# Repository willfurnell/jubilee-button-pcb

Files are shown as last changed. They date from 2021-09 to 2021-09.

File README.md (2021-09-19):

# jubilee-button-pcb

PCB for the Jubilee Line button replacement PCB

Created using KiCad

Check out some sample code here: https://github.com/willfurnell/jubilee-hue

You should be able to send this straight off to JLCPCB if you want one - or contact me as I did a bulk order and may have some to post out!

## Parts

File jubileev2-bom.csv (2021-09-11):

Reference | Quantity | Value | Footprint | LCSC Part #
C1, C2, C3, | 3 | 10uF | SMD_5x5.4mm | C72487
C5, | 1 | 10uF | 0805 | C15850
C6, C9, C11, C12, | 4 | 0.1uF | 0805 | C49678
C7, C8, | 2 | 47pF | 0805 | C14857
C10, | 1 | 4.7uF | 0805 | C1779
D1, | 1 | POWER_LED | 0805 | C2297
D2, | 1 | D_Schottky | SOD-123 | C8598
D3, | 1 | D | SOD-123 | C8598
D4, | 1 | ESP_LED | SOD-123 | C8598
D5, | 1 | D_Small | 0805 | C2297
Q1, Q2, | 2 | MMBT3904 | SOT-23 | C20526
Q3, | 1 | PZT2222A | SOT-223 | C189428
R1, | 1 | 1K | 0805 | C17513
R2, R3, R4, R5, R8, R9, | 6 | 10K | 0805 | C17414
R6, R7, | 2 | 27 | 0805 | C17544
R10, | 1 | 5K6 | 0805 | C28636
R11, | 1 | 50 | 0805 | C17408
R12, | 1 | 100R | 0805 | C17408
SW1, | 1 | BOOT | SMD-4_6.0x6.0x4.5P-1 | C136669
SW2, | 1 | RESET | SMD-4_6.0x6.0x4.5P-1 | C136669
U1, | 1 | AMS1117-3.3 | SOT-223 | C6186
U2, | 1 | AMS1117-5.0 | SOT-223 | C6187
U3, | 1 | ESP32-WROOM-32D | SMD-38_EP_18.0x25.5x1.27P | C473012
U4, | 1 | FT231XQ | QFN-20_EP_4.0x4.0x0.5P | C132159
U5, | 1 | 74HC14 | SOIC-14_3.9x8.7x1.27P | C5605

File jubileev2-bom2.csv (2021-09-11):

Reference | Quantity | Value | Footprint | LCSC Part #
C1, C2, C3, | 3 | 10uF | SMD_5x5.4mm | C72487
C4, C6, | 2 | 22pF | 0805 | C1804
C5, | 1 | 10uF | 0805 | C15850
C7, | 1 | 100nF | 0805 | C49678
C12, | 1 | 0.1uF | 0805 | C49678
D1, | 1 | POWER_LED | 0805 | C2297
D2, | 1 | D_Schottky | SOD-123 | C8598
D3, | 1 | D | SOD-123 | C8598
D4, | 1 | ESP_LED | 0805 | C2297
D5, | 1 | D_Small | SOD-123 | C8598
Q1, Q2, | 2 | MMBT3904 | SOT-23 | C20526
Q3, | 1 | PZT2222A | SOT-223 | C189428
R1, | 1 | 1K | 0805 | C17513
R2, R3, R4, R5, R8, R9, | 6 | 10K | 0805 | C17414
R10, | 1 | 5K6 | 0805 | C28636
R11, | 1 | 50 | 0805 | C17408
R12, | 1 | 100R | 0805 | C17408
SW1, | 1 | BOOT | SMD-4_6.0x6.0x4.5P-1 | C136669
SW2, | 1 | RESET | SMD-4_6.0x6.0x4.5P-1 | C136669
U1, | 1 | AMS1117-3.3 | SOT-223 | C6186
U2, | 1 | AMS1117-5.0 | SOT-223 | C6187
U3, | 1 | ESP32-WROOM-32D | SMD-38_EP_18.0x25.5x1.27P | C473012
U4, | 1 | CH340G | SOIC-16_3.9x9.9x1.27P | C14267
U5, | 1 | 74HC14 | SOIC-14_3.9x8.7x1.27P | C5605
Y1, | 1 | 12Mhz | SMD-3225_4P | C9002

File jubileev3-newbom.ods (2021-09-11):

Reference | Footprint | Quantity | Value | LCSC Part #
R3 | 0805 | 1 | 4.7K | C17673 (https://lcsc.com/product-detail/Chip-Resistor-Surface-Mount_Uniroyal-Elec-0805W8F4701T5E_C17673.html/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)
IC1 | QFN-24_EP_4.0x4.0x0.5P | 1 | CP2104-F03-GMR | C47742 (https://lcsc.com/product-detail/USB_SILICON-LABS_CP2104-F03-GM_CP2104-F03-GM_C47742.html/?href=jlc-SMT)
C11,C3,C2,C1,C5 | 0805 | 5 | 10uF | C15850 (https://lcsc.com/product-detail/Multilayer-Ceramic-Capacitors-MLCC-SMD-SMT_SAMSUNG_CL21A106KAYNNNE_10uF-106-10-25V_C15850.html/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)
C7 | 0805 | 1 | 0.1uF | C49678
C6,C4,C10,C9,C8,C12 | 0805 | 6 | 0.1uF | C49678
ANT1 | SMD-38_EP_18.0x25.5x1.27P | 1 | ESP32-WROOM-32D | C473012
IC2 | SOIC-14_3.9x8.7x1.27P | 1 | 74HC14D,653 | C5605
R12 | 0805 | 1 | 100R | C17408 (https://lcsc.com/product-detail/Chip-Resistor-Surface-Mount_Uniroyal-Elec-0805W8F1000T5E_C17408.html/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)
D4 | 0805 | 1 | ESP_LED | C2297
R2,R4,R5,R8,R9 | 0805 | 5 | 10K | C17414
F1 | 1206 | 1 | Polyfuse | C151162 (https://lcsc.com/product-detail/PTC-Resettable-Fuses_Littelfuse-1206L050-15YR_C151162.html/?href=jlc-SMT)
D5 | SOD-123 | 1 | D_Small | C8598
D3 | SOD-123 | 1 | D | C8598
D2 | SOD-123 | 1 | D_Schottky | C8598
D1 | 0805 | 1 | POWER_LED | C2297
Q1,Q2 | SOT-23 | 2 | MMBT3904 | C20526
Q3 | SOT-223 | 1 | PZT2222A | C189428
R1 | 0805 | 1 | 1K | C17513
R10 | 0805 | 1 | 5K6 | C28636
R11 | 0805 | 1 | 50 | C17408
U1 | SOT-223 | 1 | AMS1117-3.3 | C6186
U2 | SOT-223 | 1 | AMS1117-5.0 | C6187

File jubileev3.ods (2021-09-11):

Reference | Footprint | Quantity | Value | LCSC Part #
C6,C4,C10,C9,C8,C12 | 0805 | 6 | 0.1uF | C49678
ANT1 | SMD-38_EP_18.0x25.5x1.27P | 1 | ESP32-WROOM-32D | C473012
IC2 | SOIC-14_3.9x8.7x1.27P | 1 | 74HC14D,653 | C5605
R12 | R_0805_2012Metric | 1 | 100R
D4 | 0805 | 1 | ESP_LED | C2297
IC1 | QFN50P500X500X100-29N-D | 1 | CP2104-GMR
C3,C2,C1,C5 | C_0805_2012Metric | 4 | 10uF
R2,R4,R5,R8,R9 | 0805 | 5 | 10K | C17414
F1 | Fuse_1206_3216Metric | 1 | Polyfuse
D5 | SOD-123 | 1 | D_Small | C8598
D3 | SOD-123 | 1 | D | C8598
D2 | SOD-123 | 1 | D_Schottky | C8598
D1 | LED_0805_2012Metric | 1 | POWER_LED | C2297
J2 | USB_Micro-B_Amphenol_10118194_Horizontal | 1 | USB_B_Micro
Q1,Q2 | SOT-23 | 2 | MMBT3904 | C20526
Q3 | SOT-223 | 1 | PZT2222A | C189428
R1 | 0805 | 1 | 1K | C17513
R10 | 0805 | 1 | 5K6 | C28636
R11 | 0805 | 1 | 50 | C17408
U1 | SOT-223 | 1 | AMS1117-3.3 | C6186
U2 | SOT-223 | 1 | AMS1117-5.0 | C6187

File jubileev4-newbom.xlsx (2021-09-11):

Reference | Footprint | Quantity | Value | LCSC Part #
U3 | SOP-16_3.9x10.1x1.27P | 1 | CH340C | C84681 (https://lcsc.com/product-detail/USB-ICs_WCH-Jiangsu-Qin-Heng-CH340C_C84681.html/?href=jlc-SMT)
C11,C4,C8 | 0805 | 3 | 100nF | C49678 (https://lcsc.com/product-detail/Multilayer-Ceramic-Capacitors-MLCC-SMD-SMT_100nF-104-10-50V_C49678.html/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)
USB1 | TYPE-C-31_L8.94_W7.3 Copy | 1 | HRO-TYPE-C-31-M-12 | C165948 (https://lcsc.com/product-detail/USB-Connectors_Korean-Hroparts-Elec-TYPE-C-31-M-12_C165948.html/?href=jlc-SMT)
R4,R3 | 0805 | 2 | 5.1K | C27834 (https://lcsc.com/product-detail/Chip-Resistor-Surface-Mount_UNI-ROYAL-Uniroyal-Elec-0805W8F5101T5E_C27834.html/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)
Q1 | SOT-363 | 1 | UMH3N | C62892 (https://lcsc.com/product-detail/Digital-Transistors_Changjiang-Electronics-Tech-CJ-UMH3N_C62892.html/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)
C10,C3,C2,C1,C5 | 0805 | 5 | 10uF | C15850 (https://lcsc.com/product-detail/Multilayer-Ceramic-Capacitors-MLCC-SMD-SMT_SAMSUNG_CL21A106KAYNNNE_10uF-106-10-25V_C15850.html/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)
C6,C12 | 0805 | 2 | 0.1uF | C49678
ANT1 | SMD-38_EP_18.0x25.5x1.27P | 1 | ESP32-WROOM-32D | C473012
IC2 | SOIC-14_3.9x8.7x1.27P | 1 | 74HC14D,653 | C5605
R12,R1 | 0805 | 2 | 2K | C17604 (https://lcsc.com/product-detail/Chip-Resistor-Surface-Mount_UNI-ROYAL-Uniroyal-Elec-0805W8F2001T5E_C17604.html/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)
D4 | 0805 | 1 | ESP_LED | C2297
R2,R8,R9 | 0805 | 3 | 10K | C17414
F1 | 1206 | 1 | Polyfuse | C151162 (https://lcsc.com/product-detail/PTC-Resettable-Fuses_Littelfuse-1206L050-15YR_C151162.html/?href=jlc-SMT)
D5 | SOD-123 | 1 | D_Small | C8598
D3 | SOD-123 | 1 | D | C8598
D2 | SOD-123 | 1 | D_Schottky | C8598
D1 | 0805 | 1 | POWER_LED | C2297
Q3 | SOT-223 | 1 | PZT2222A | C189428
R10 | 0805 | 1 | 5K6 | C28636
R11 | 0805 | 1 | 50 | C17408
U1 | SOT-223 | 1 | AMS1117-3.3 | C6186
U2 | SOT-223 | 1 | AMS1117-5.0 | C6187

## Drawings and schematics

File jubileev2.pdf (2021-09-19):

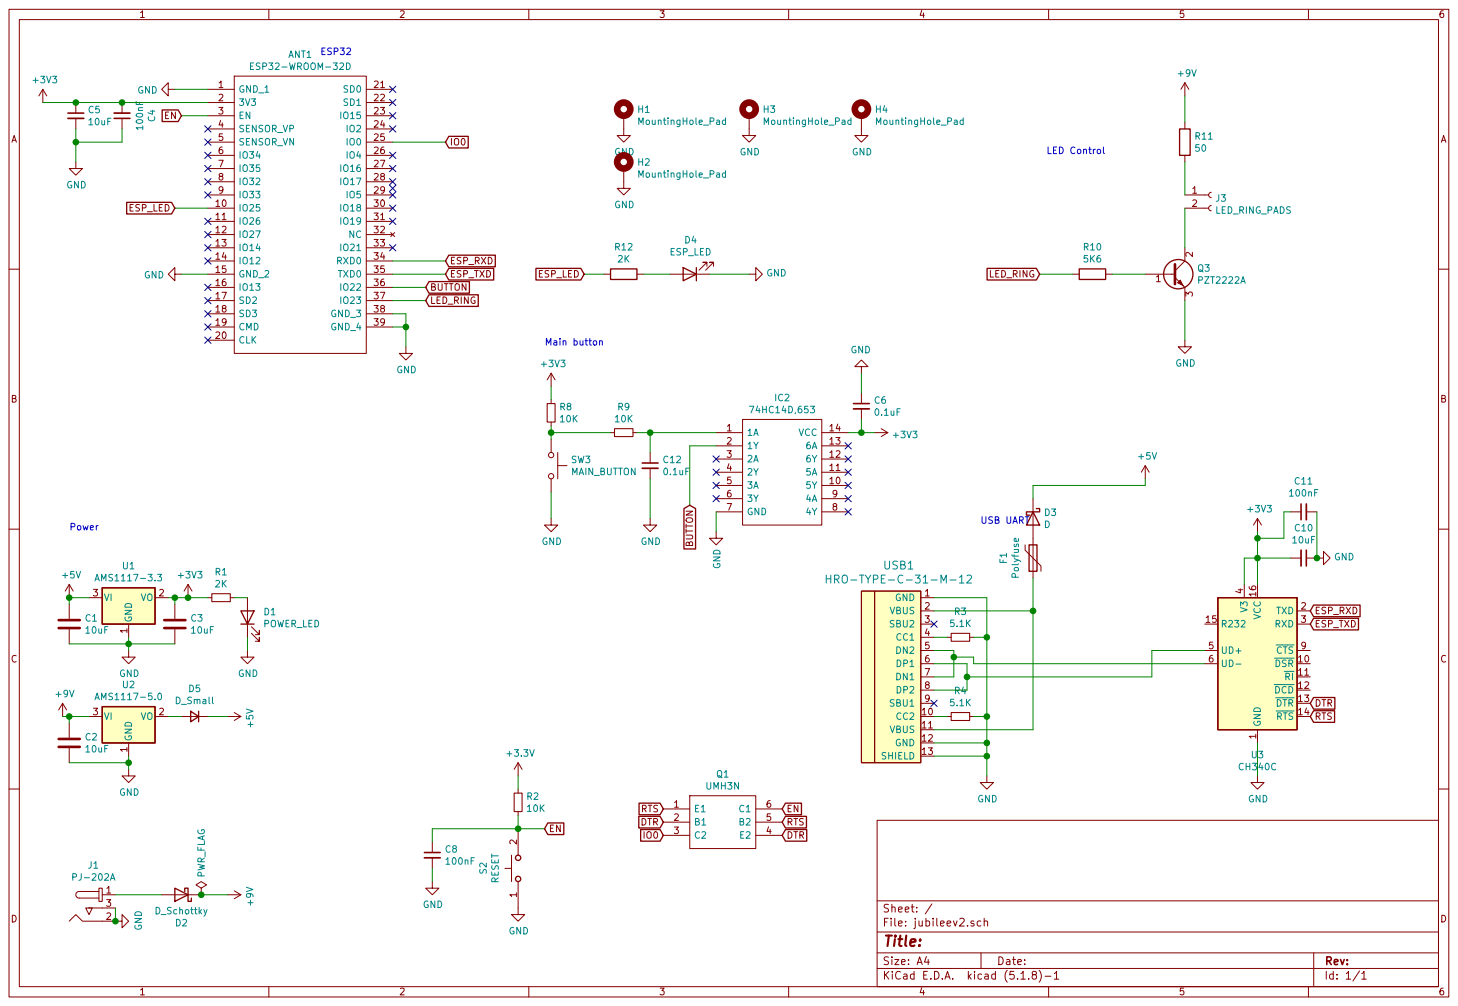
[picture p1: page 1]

HRO-TYPE-C-31-M-12 GNDGND GND

1 VO 2 VI 3 U1 AMS1117-3.3 RTS DTR

1 DSR 10 RI 11 DCD 12 DTR 13 RTS 14 R232 15 VCC 16 TXD 2 RXD 3 V3

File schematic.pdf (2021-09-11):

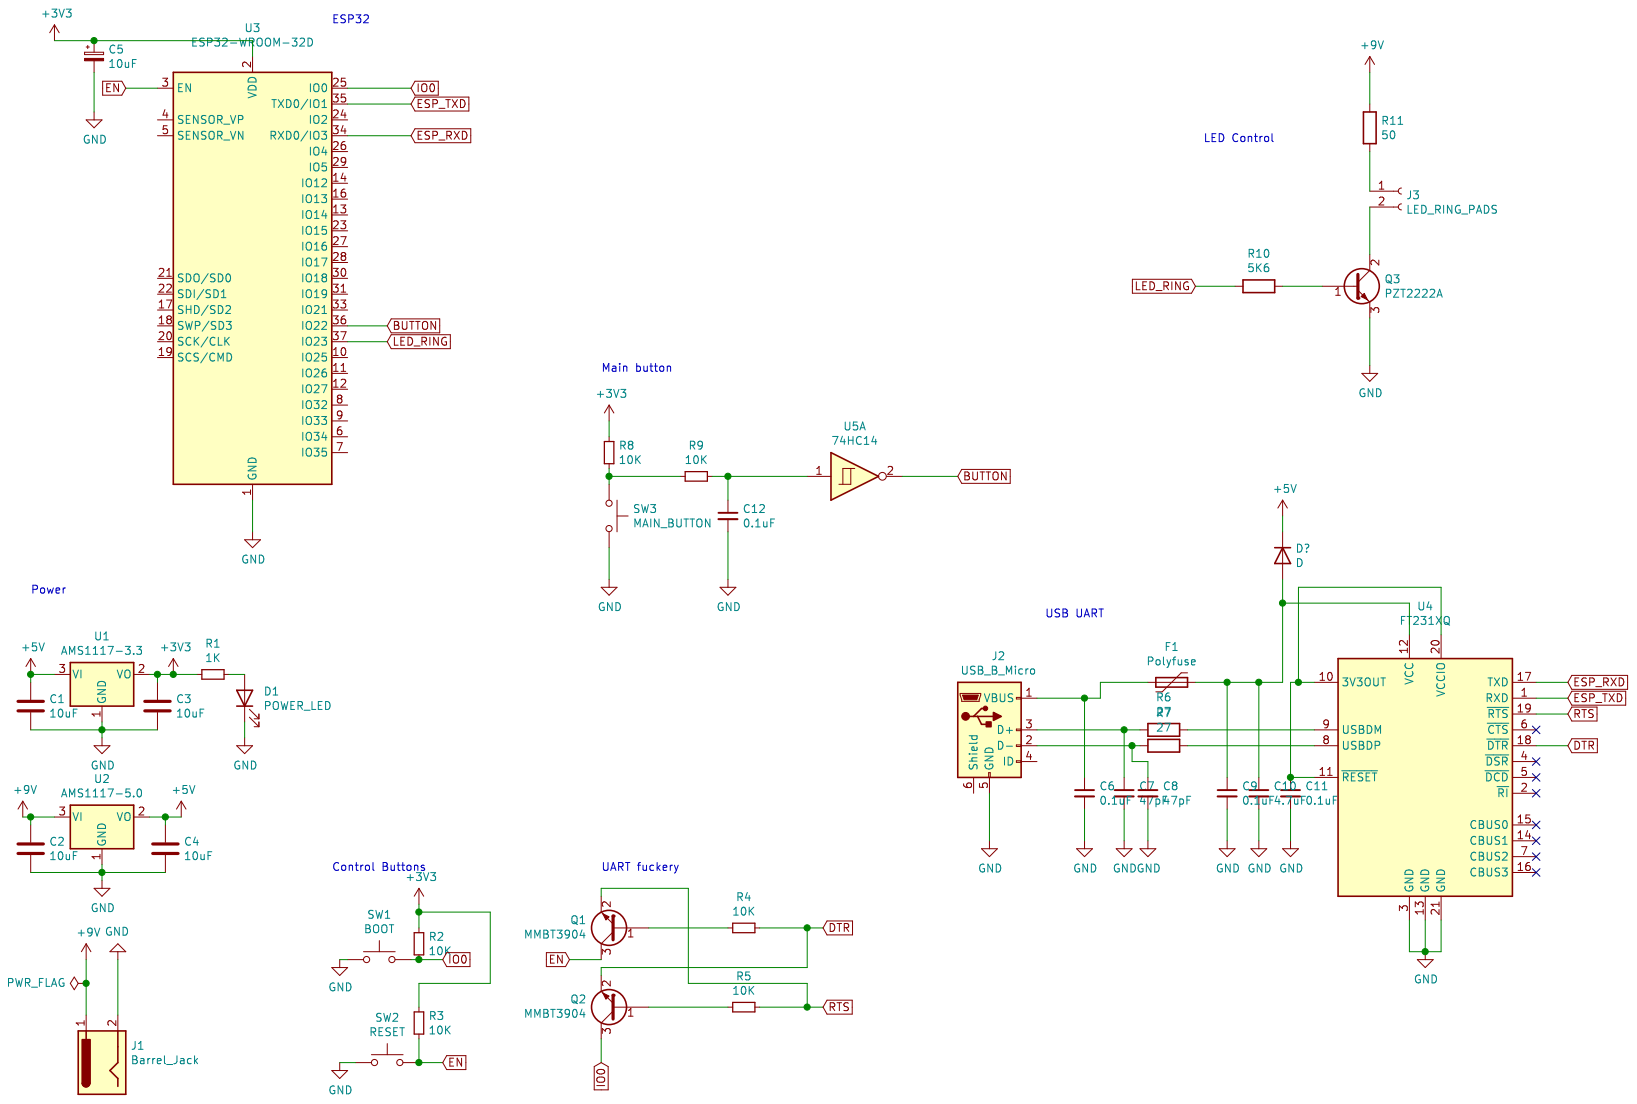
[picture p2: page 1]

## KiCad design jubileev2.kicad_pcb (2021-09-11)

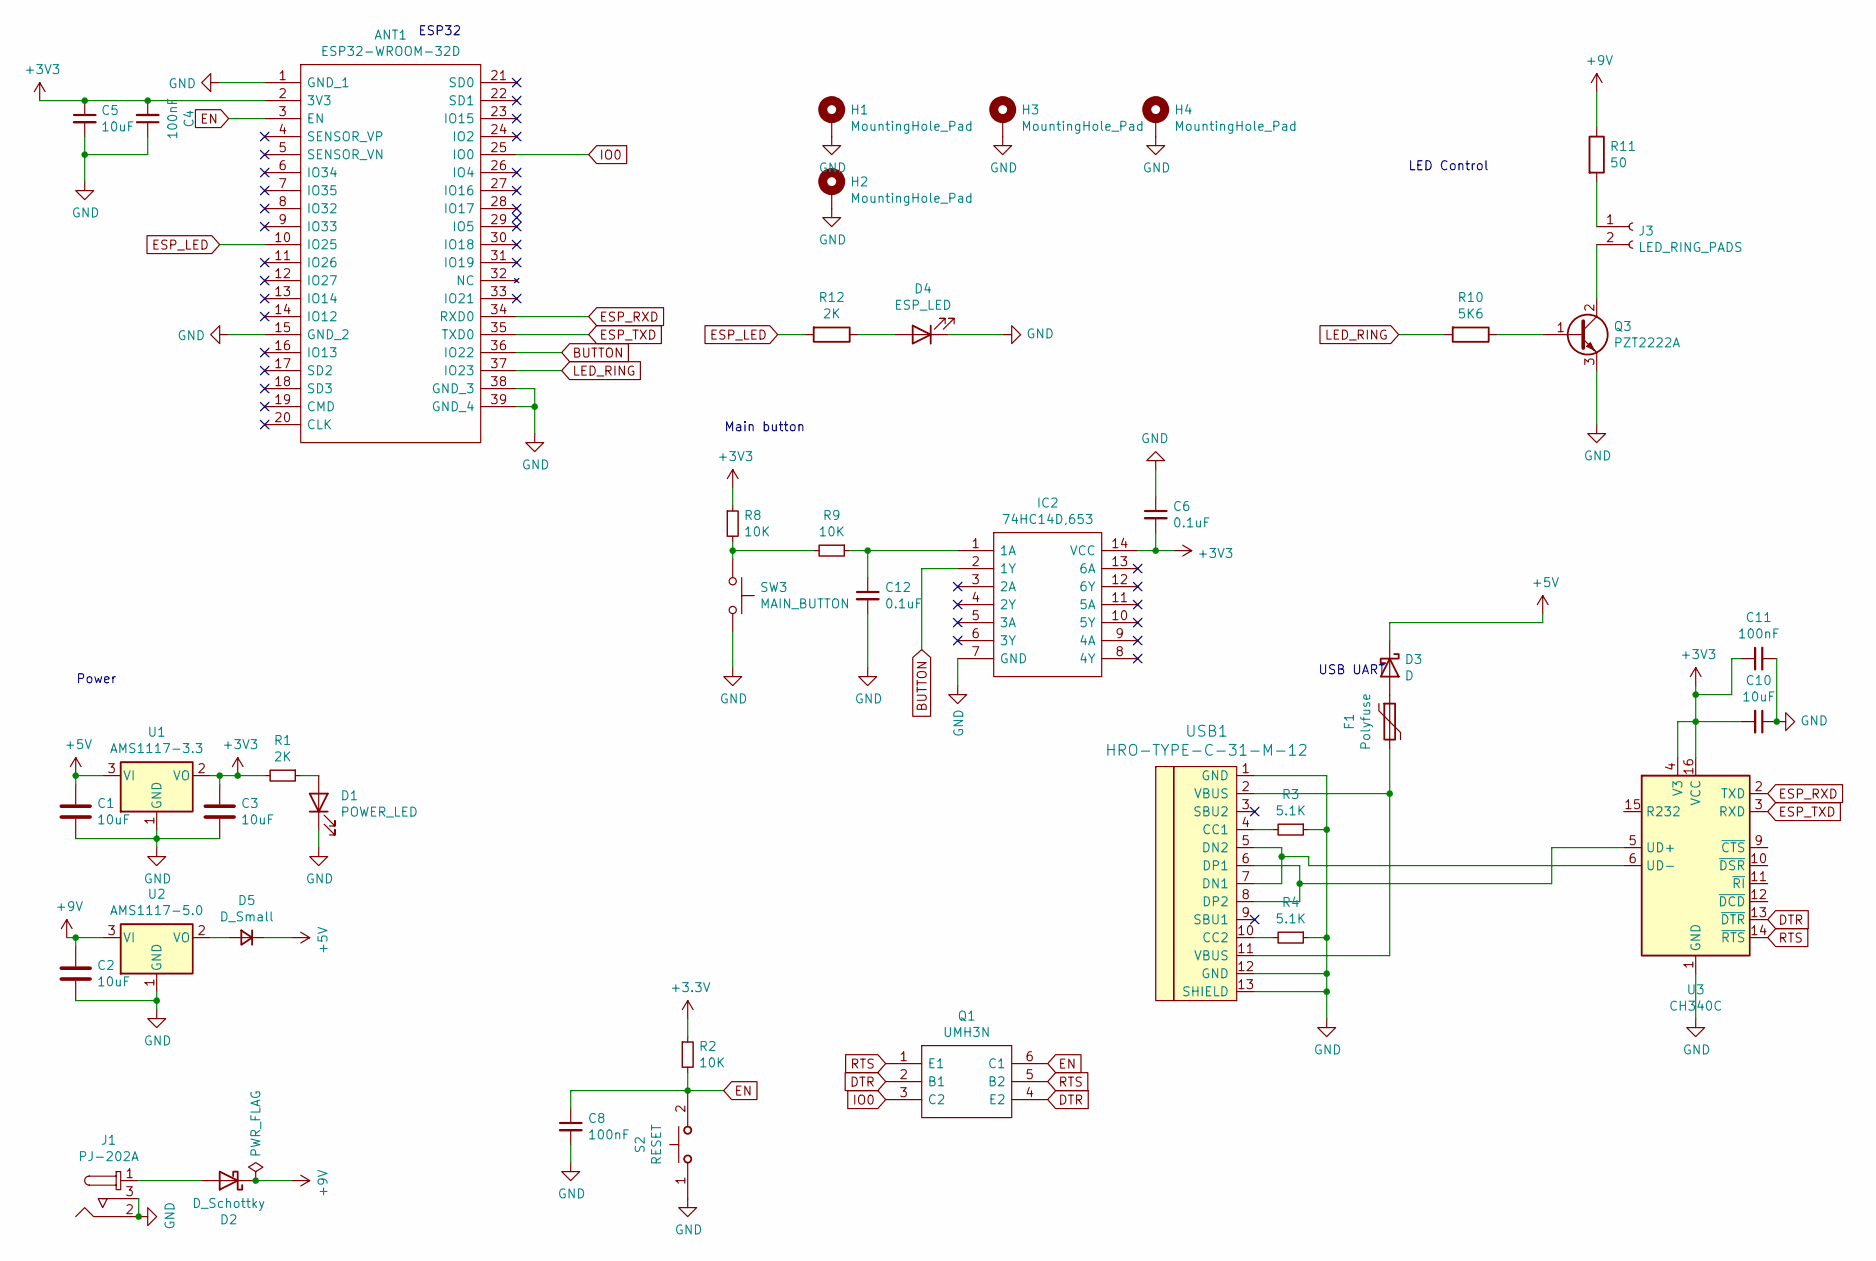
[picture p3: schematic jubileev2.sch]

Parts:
ANT1: ESP32-WROOM-32D; ESP32WROOM32D; Manufacturer_Part_Number ESP32-WROOM-32D; Mouser Part Number N/A
C1, C2, C3, C5, C10: 10uF; C_0805_2012Metric
C4, C8, C11: 100nF; C_0805_2012Metric
C6, C12: 0.1uF; C_0805_2012Metric
D1: POWER_LED; LED_0805_2012Metric
D2: D_Schottky; D_SOD-123
D3: D; D_SOD-123
D4: ESP_LED; LED_0805_2012Metric
D5: D_Small; D_SOD-123
F1: Polyfuse; Fuse_1206_3216Metric
H1, H2, H3, H4: MountingHole_Pad; MountingHole_3.5mm_Pad_TopBottom
IC2: 74HC14D,653; SOIC127P600X175-14N; Manufacturer_Part_Number 74HC14D,653; Mouser Part Number 771-74HC14D-T
J1: PJ-202A; Barrel_Jack_5.5mmODx2.1mmID_PJ-202A; MPN PJ-202A; Digi-Key_PN CP-202A-ND
J3: LED_RING_PADS; SolderWire-0.5sqmm_1x02_P4.6mm_D0.9mm_OD2.1mm
Q1: UMH3N; SOT65P230X110-6N; Manufacturer_Part_Number UMH3N
Q3: PZT2222A; SOT-223-3_TabPin2
R1, R12: 2K; R_0805_2012Metric
R2, R8, R9: 10K; R_0805_2012Metric
R3, R4: 5.1K; R_0805_2012Metric
R10: 5K6; R_0805_2012Metric
R11: 50; R_0805_2012Metric
S2: RESET; FSM2JRT; Mouser Part Number 506-FSM2JRT
SW3: MAIN_BUTTON; SolderWire-0.5sqmm_1x02_P4.6mm_D0.9mm_OD2.1mm
U1: AMS1117-3.3; SOT-223-3_TabPin2
U2: AMS1117-5.0; SOT-223-3_TabPin2
U3: CH340C; SOIC-16_3.9x9.9mm_P1.27mm
USB1: HRO-TYPE-C-31-M-12

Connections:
+5V: C1.1, D3.1 (K), D5.1 (K), U1.3 (VI)
+9V: C2.1, D2.1 (K), R11.1, U2.3 (VI)
BUTTON: ANT1.36 (IO22), IC2.2 (1Y)
DTR: Q1.2 (B1), Q1.4 (E2), U3.13 (~DTR)
EN: ANT1.3 (EN), C8.1, Q1.6 (C1), R2.2, S2.2
ESP_LED: ANT1.10 (IO25), R12.2
ESP_RXD: ANT1.34 (RXD0), U3.2 (TXD)
ESP_TXD: ANT1.35 (TXD0), U3.3 (RXD)
GND: ANT1.1 (GND_1), ANT1.15 (GND_2), ANT1.38 (GND_3), ANT1.39 (GND_4), C1.2, C2.2, C3.2, C4.1, C5.2, C6.1, C8.2, C10.1, C11.2, C12.2, D1.1 (K), D4.1 (K), H1.1, H2.1, H3.1, H4.1, IC2.7 (GND), J1.2, J1.3, Q3.3 (E), R3.1, R4.1, S2.1, SW3.2, U1.1 (GND), U2.1 (GND), U3.1 (GND), USB1.1 (GND), USB1.12 (GND), USB1.13 (SHIELD)
IO0: ANT1.25 (IO0), Q1.3 (C2)
LED_RING: ANT1.37 (IO23), R10.2
unnamed: C12.1, IC2.1 (1A), R9.1
unnamed: D1.2 (A), R1.1
unnamed: D2.2 (A), J1.1
unnamed: D3.2 (A), F1.1
unnamed: D4.2 (A), R12.1
unnamed: D5.2 (A), U2.2 (VO)
unnamed: F1.2, USB1.2 (VBUS), USB1.11 (VBUS)
unnamed: J3.1, R11.2
unnamed: J3.2, Q3.2 (C)
unnamed: Q3.1 (B), R10.1
unnamed: R3.2, USB1.4 (CC1)
unnamed: R4.2, USB1.10 (CC2)
unnamed: R8.2, R9.2, SW3.1
unnamed: U3.5 (UD+), USB1.6 (DP1), USB1.8 (DP2)
unnamed: U3.6 (UD-), USB1.5 (DN2), USB1.7 (DN1)
RTS: Q1.1 (E1), Q1.5 (B2), U3.14 (~RTS)

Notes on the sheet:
USB UART
Power
Main button
LED Control
ESP32

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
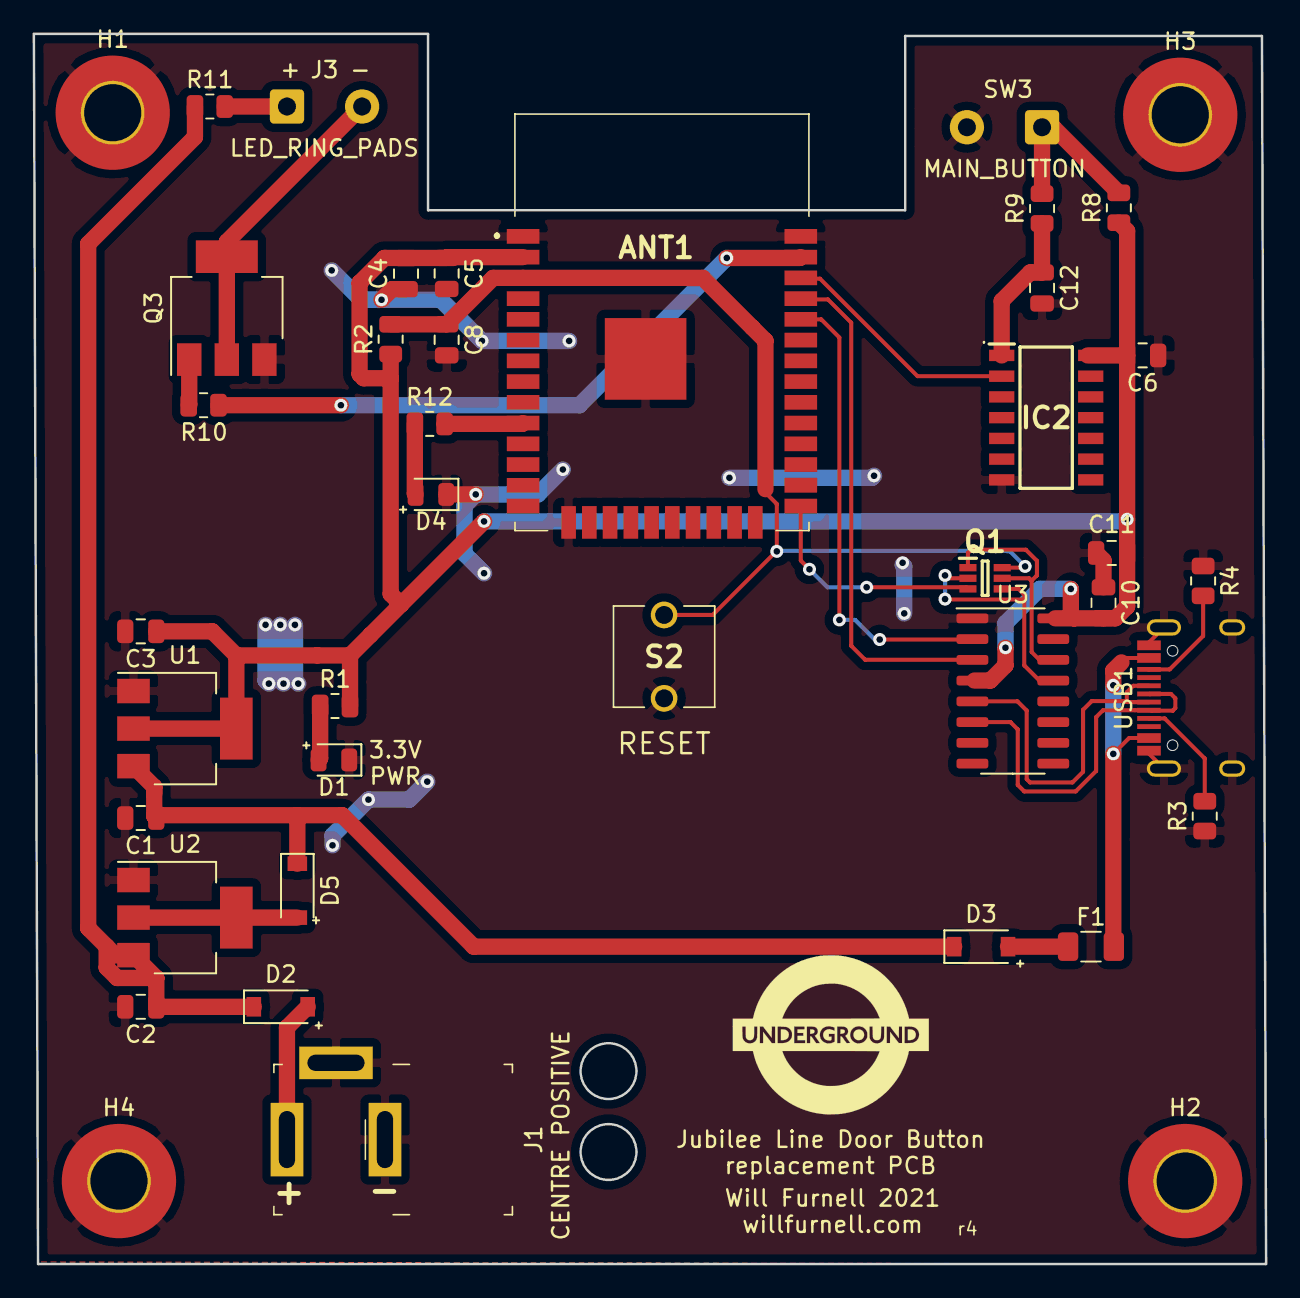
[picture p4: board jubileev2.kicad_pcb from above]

Board: 2 copper layers, 75.4 x 75.3 mm, 41 parts (0 on the bottom side), 28 nets.
